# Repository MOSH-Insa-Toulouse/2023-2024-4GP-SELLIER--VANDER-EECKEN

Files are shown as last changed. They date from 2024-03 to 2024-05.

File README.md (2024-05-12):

<h1 align="center">📈 Projet capteur graphène 📉</h1>
<h2 align="center">👨‍🔬 Par VANDER-EECKEN Néo et SELLIÉ Pierre 👨‍🔬</h2>
<h3 align="center">🏫 Pour l'INSA de Toulouse, département du Génie Physique, année 2023 - 2024 🎓</h3>

<p align="center">
  <a href="http://www.gnu.org/licenses/gpl-3.0">
    
  </a>
</p>



<h1 align="center">🔩 Mesure de contrainte avec capteur graphène sous Arduino 🤖</h1>

## 📝 Description

Ce projet introduit une approche novatrice pour la mesure de contrainte en exploitant les propriétés uniques du graphène à travers un capteur dédié, envisagé comme une alternative prometteuse aux jauges de contrainte conventionnelles. Grâce à l'emploi du graphène, connu pour sa sensibilité et sa flexibilité, ce capteur offre un potentiel intéressant pour une variété d'applications de mesure. Le système est bâti autour d'une plateforme Arduino, facilitant ainsi son accessibilité et sa manipulation pour tous.

Le projet inclut un circuit d'amplification pour le signal du capteur en graphène, assurant une précision accrue des mesures. Un potentiomètre digital permet d'ajuster le gain de ce circuit, offrant ainsi une calibration précise selon les besoins spécifiques de l'application. Cette approche est complétée par des modules tels que le Bluetooth, un écran OLED et un encodeur rotatoire, qui enrichissent l'expérience utilisateur et la fonctionnalité du système.

En complément de la programmation Arduino, ce projet est accompagné de fichiers KiCad détaillant le design d'un Shield UNO personnalisé. Cette approche modulaire facilite le montage et l'intégration de l'ensemble des composants, permettant ainsi une grande flexibilité dans la configuration du système.

## 🌟 Fonctionnalités

- **Capteur de contrainte en graphène** : Exploite les propriétés du graphène pour une mesure de contrainte.
- **Circuit d'amplification avec réglage** : Potentiomètre digital pour ajuster le gain.
- **Modules intégrés** : Communication Bluetooth, affichage sur écran OLED et interaction utilisateur via encodeur rotatoire.
- **Design modulaire** : Fichiers KiCad pour un Shield UNO personnalisé.

Pour plus d'informations, vous pouvez retrouver la datasheet du produit [ici](https://github.com/MOSH-Insa-Toulouse/2023-2024-4GP-SELLIER--VANDER-EECKEN/blob/main/Datasheet.pdf).

## 📦 Matériel nécessaire

- Capteur graphène (à fabriquer soi-même)
- Arduino UNO (https://store.arduino.cc/products/arduino-uno-rev3)
- Circuit d'amplification : LTC1050#CN8 + 2x100kΩ ; 10kΩ ; 1kΩ ; 3x100nF ; 1µF (https://www.analog.com/en/products/ltc1050.html)
- Potentiomètre digital : MCP41050-IP (https://www.microchip.com/en-us/product/mcp41050)
- Module Bluetooth : HC-05 (https://www.gotronic.fr/art-module-bluetooth-hc05-26097.htm)
- Écran OLED : SSD1306 (https://electropeak.com/0-96-oled-64x128-display-module)
- Encodeur rotatoire (https://www.az-delivery.de/fr/products/drehimpulsgeber-modul)
- Capteur FLEX (https://www.kiwi-electronics.com/en/short-flex-bend-sensor-2172)

## 🔧 Installation

1. Assemblez le circuit selon les schémas fournis dans les fichiers KiCad.
2. Connectez les modules et le capteur en suivant le schéma KiCad.
3. Installez l'IDE Arduino et installez la librairie "U8glib"
4. Téléchargez le code source sur votre Arduino UNO.

## 🖥️ Utilisation

Utilisez l'encodeur rotatoire pour naviguer dans le menu de l'écran OLED.

## 🤝 Contribuer

Les contributions sont bienvenues ! Si vous avez des idées d'amélioration, n'hésitez pas à forker le projet, soumettre des pull requests ou ouvrir des issues.

## 📜 Licence

Distribué sous la GNU General Public License (GPL), favorisant un écosystème ouvert et collaboratif.

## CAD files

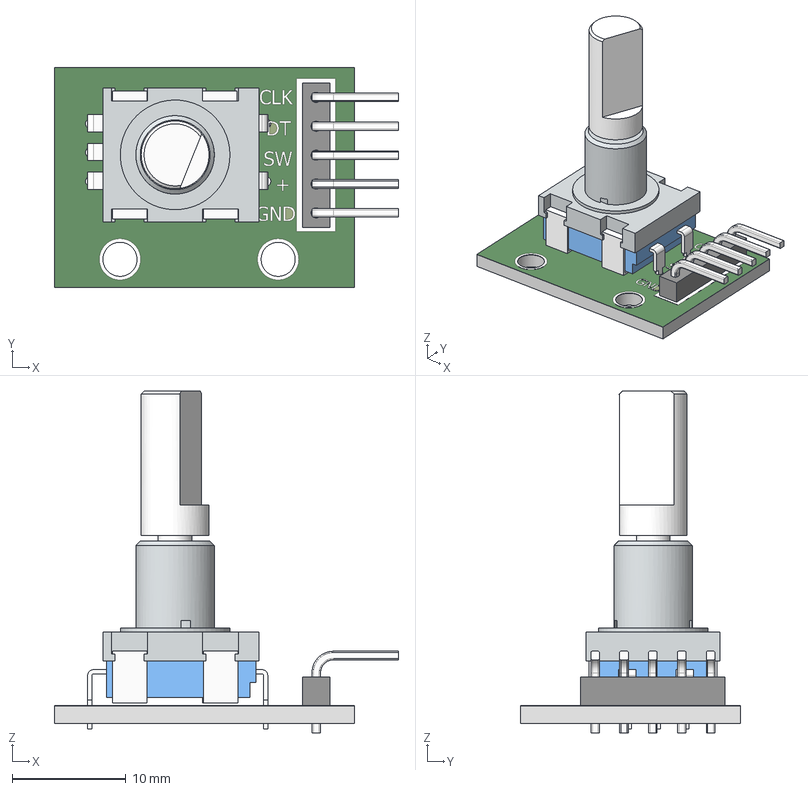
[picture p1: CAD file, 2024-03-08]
Fichiers KiCad/3D Models/KY-040.step
30.3 x 19.3 x 30.1 mm
pcb
mtg flange
body_encoder
5 pin header
90d pin_header x 5
decal_encoder
shaft_encoder

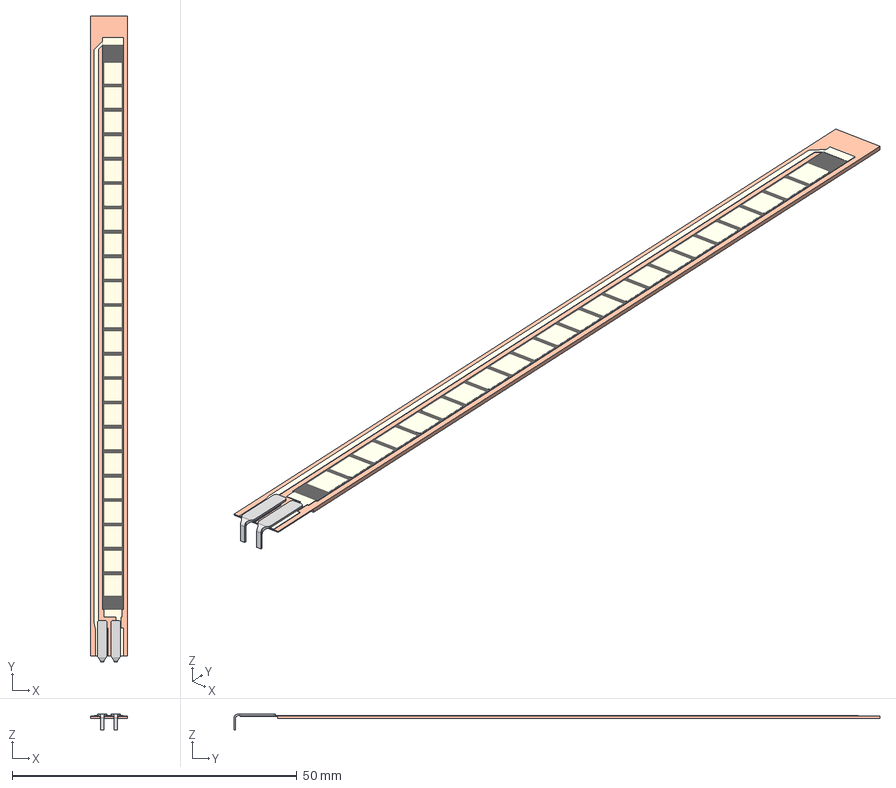
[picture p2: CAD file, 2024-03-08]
Fichiers KiCad/3D Models/Flex.stp
6.45 x 113.5 x 2.77 mm
FS-L-0095-103-ST - Base
FS-L-0095-103-ST - Top

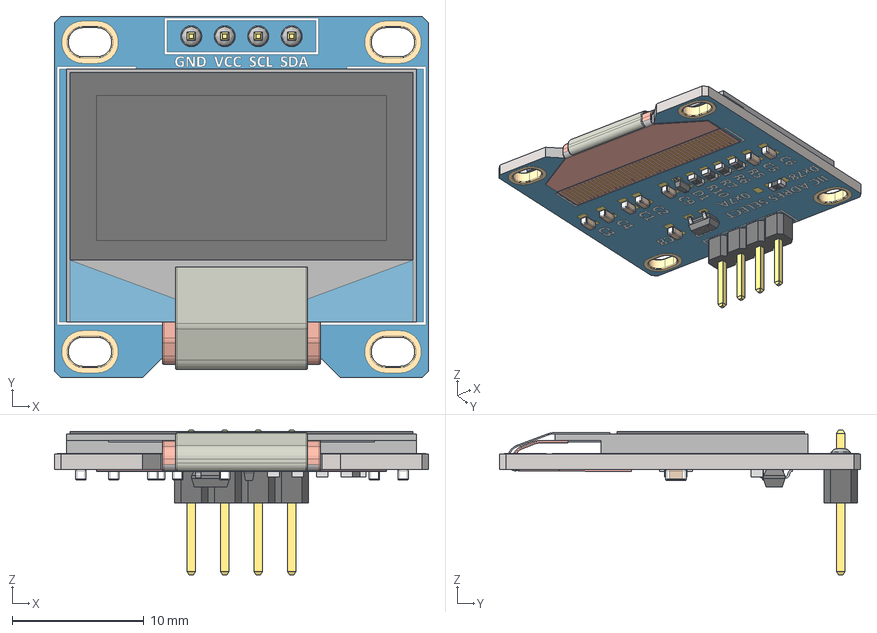
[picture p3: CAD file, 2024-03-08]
Fichiers KiCad/3D Models/SSD1306.stp
28.4 x 27.4 x 11.0 mm
SOT-23_TOR
RES_CR16_MTK_1 x 4
RES_CR16_MTK
SOD323F_DIO

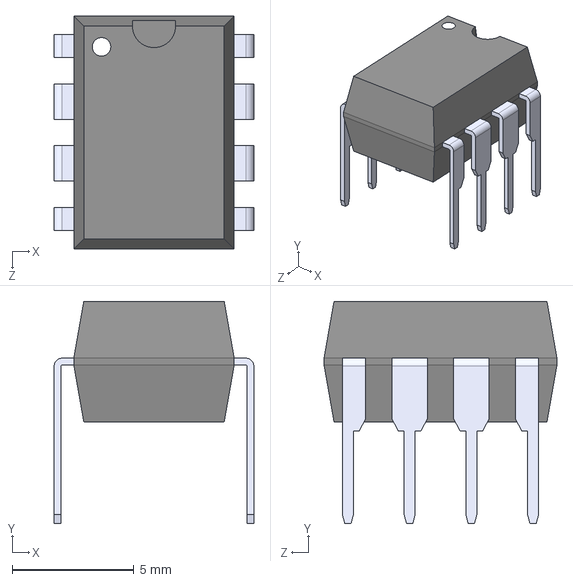
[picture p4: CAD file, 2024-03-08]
Fichiers KiCad/3D Models/LTC1050#CN8.step
8.22 x 9.14 x 9.59 mm

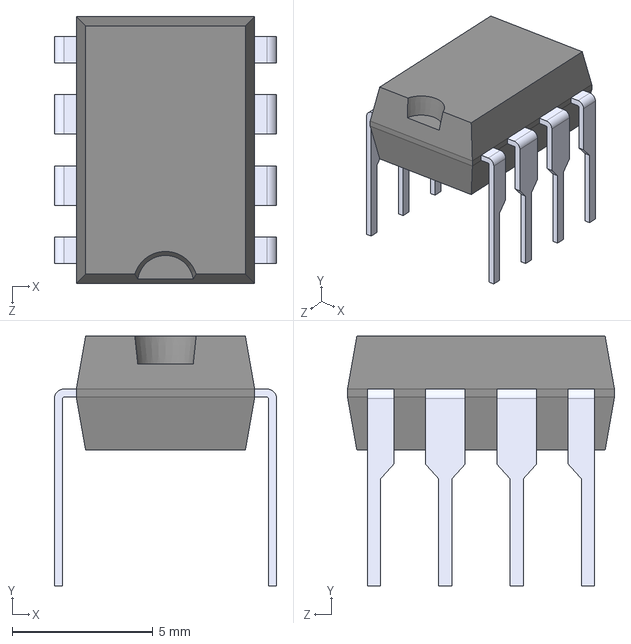
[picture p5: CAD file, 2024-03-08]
Fichiers KiCad/3D Models/MCP41050-I_P.step
7.91 x 8.89 x 9.50 mm

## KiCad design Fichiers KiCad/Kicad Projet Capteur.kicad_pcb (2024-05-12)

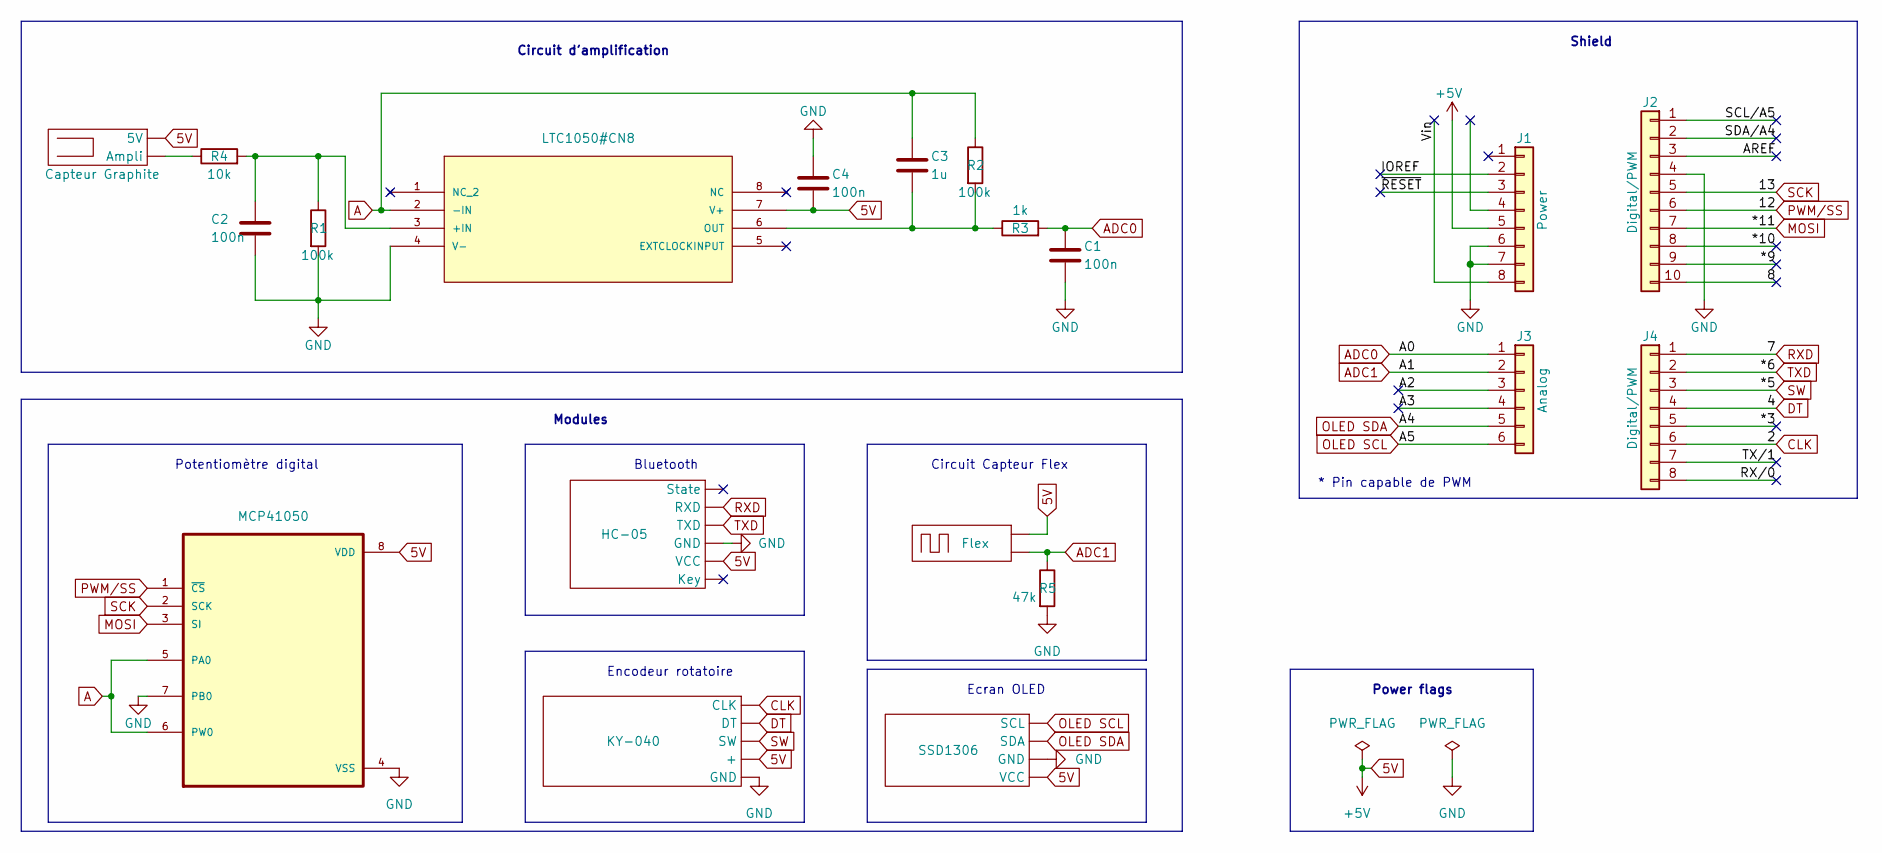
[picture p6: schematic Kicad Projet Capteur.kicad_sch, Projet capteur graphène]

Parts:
C1, C2, C4: 100n; C_Disc_D4.3mm_W1.9mm_P5.00mm
C3: 1u; C_Rect_L7.0mm_W4.5mm_P5.00mm
Capteur-Graphite1: Capteur Graphite; PinSocket_1x02_P2.54mm_Vertical
Flex1: Flex; PinSocket_1x02_P2.54mm_Vertical
HC-5: HC-05; PinSocket_1x06_P2.54mm_Vertical
J1: Power; PinSocket_1x08_P2.54mm_Vertical
J2: Digital/PWM; PinSocket_1x10_P2.54mm_Vertical
J3: Analog; PinSocket_1x06_P2.54mm_Vertical
J4: Digital/PWM; PinSocket_1x08_P2.54mm_Vertical
Pot1: KY-040; PinSocket_1x05_P2.54mm_Vertical
R1, R2: 100k; R_Axial_DIN0204_L3.6mm_D1.6mm_P5.08mm_Horizontal
R3: 1k; R_Axial_DIN0204_L3.6mm_D1.6mm_P5.08mm_Horizontal
R4: 10k; R_Axial_DIN0204_L3.6mm_D1.6mm_P5.08mm_Horizontal
R5: 47k; R_Axial_DIN0204_L3.6mm_D1.6mm_P5.08mm_Horizontal
SSD1306: SSD1306; PinSocket_1x04_P2.54mm_Vertical
U1: LTC1050#CN8; LTC1050; MANUFACTURER_PART_NUMBER ltc1050cn8
U2: MCP41050; MCP

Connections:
5V: C4.2, Capteur-Graphite1.1 (5V), Flex1.1 (+), HC-5.5 (VCC), J1.5, Pot1.4 (+), SSD1306.4 (VCC), U1.7 (V+), U2.8 (VDD)
/8: J2.10
/*3: J4.5
/*9: J2.9
/*10: J2.8
/A2: J3.3
/A3: J3.4
/AREF: J2.3
/IOREF: J1.2
/RX/0: J4.8
/SCL/A5: J2.1
/SDA/A4: J2.2
/TX/1: J4.7
/Vin: J1.8
/~RESET: J1.3
A: C3.1, R2.1, U1.2 (-IN), U2.5 (PA0), U2.6 (PW0)
ADC0: C1.1, J3.1, R3.2
ADC1: Flex1.2 (-), J3.2, R5.1
CLK: J4.6, Pot1.1 (CLK)
DT: J4.4, Pot1.2 (DT)
GND: C1.2, C2.2, C4.1, HC-5.4 (GND), J1.6, J1.7, J2.4, Pot1.5 (GND), R1.2, R5.2, SSD1306.3 (GND), U1.4 (V-), U2.4 (VSS), U2.7 (PB0)
MOSI: J2.7, U2.3 (SI)
unnamed: Capteur-Graphite1.2 (Ampli), R4.1
unnamed: C2.1, R1.1, R4.2, U1.3 (+IN)
unnamed: C3.2, R2.2, R3.1, U1.6 (OUT)
OLED SCL: J3.6, SSD1306.1 (SCL)
OLED SDA: J3.5, SSD1306.2 (SDA)
PWM/SS: J2.6, U2.1 (~CS)
RXD: HC-5.2 (RXD), J4.1
SCK: J2.5, U2.2 (SCK)
SW: J4.3, Pot1.3 (SW)
TXD: HC-5.3 (TXD), J4.2

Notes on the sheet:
Potentiomètre digital
Circuit d'amplification
Power flags
Bluetooth
Ecran OLED
Circuit Capteur Flex
* Pin capable de PWM
Modules
Shield
Encodeur rotatoire

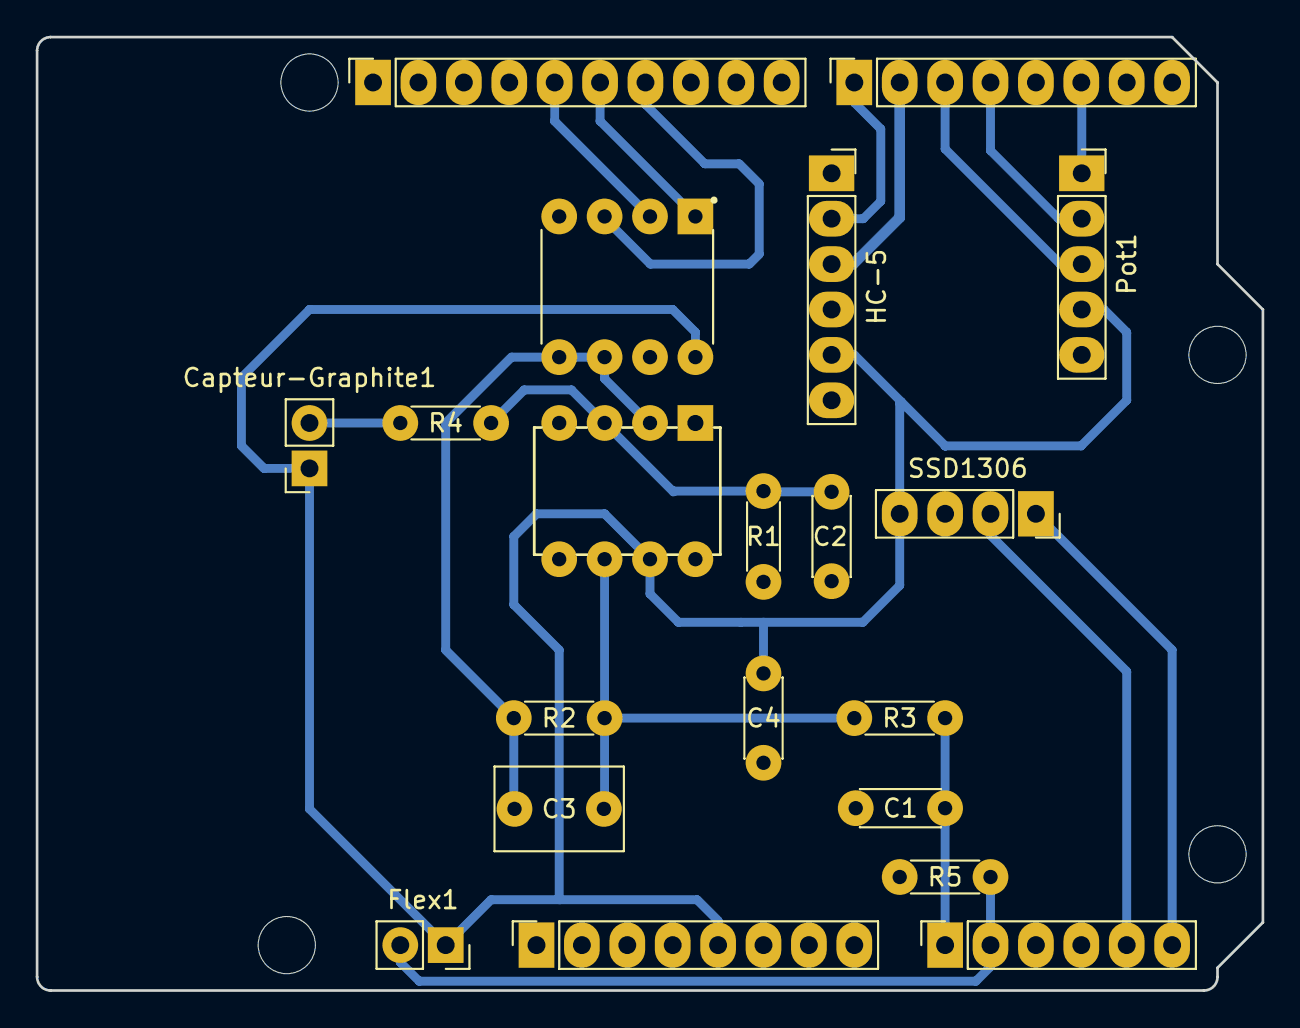
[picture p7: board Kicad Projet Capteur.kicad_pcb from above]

Board: 2 copper layers, 68.6 x 53.3 mm, 24 parts (0 on the bottom side), 18 nets.

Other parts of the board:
MH1, MH2, MH3, MH4: MountingHole_3.2mm

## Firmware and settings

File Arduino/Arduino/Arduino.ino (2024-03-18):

#include <SoftwareSerial.h>
#include <SPI.h>
#include "U8glib.h"

// Définitions des broches
#define CLK 2 // Broche 2 en tant que CLK, raccordé sur CLK du KY-040
#define DT 4 // Broche 4 en tant que DT, raccordé sur DT du KY-040
#define SW 5 // Broche 5 en tant que SW, raccordé sur SW du KY-040
#define txPin 6 // Broche 6 en tant que TX, raccordé sur TX du HC-05
#define rxPin 7 // Broche 7 en tant que RX, raccordé sur RX du HC-05
#define SS 12 // Broche 12 en tant que SS, raccordé sur SS du MCP41050
#define Ampli A0 // Broche A0 en tant que Ampli, raccordé sur la sortie du LTC1050#CN8
#define Flex A1 // Broche A1 en tant que Flex, raccordé sur le pont diviseur du capteur Flex

#define baudrate 9600 // Définition du BaudRate général
SoftwareSerial mySerial(rxPin ,txPin); // Définition du software serial

#define delai_inter_image 6 // Définition pour les animations

// Variables pour le MCP41050
const double R_max = 50000.0; // Résistance maximale du MCP41050
const double R_min = 0.0; // Résistance minimale du MCP41050
const double R_amp = 100000.0; // Résistance en sortie de l'amplificateur
const double R_wiper = 125.0; // Résistance interne du MCP41050
const double gain_max = 801; // 1 + R_amp/(R_min+R_wiper)
const double gain_min = 3; // 1 + R_amp/(R_max+R_wiper)
double R_mcp = R_max - R_wiper; // Résistance du MCP41050, par défaut maximale
double gain = 3; // Gain par défaut, le gain vaut 1 + R_amp/(R_mcp + R_wiper)
double ancien_gain = 3; // Variable utilisée pour checker un changement de gain

// Initilisation de l'écran
U8GLIB_SSD1306_128X64 u8g(U8G_I2C_OPT_DEV_0 | U8G_I2C_OPT_NO_ACK | U8G_I2C_OPT_FAST);

// Variables pour le KY-040
volatile unsigned int Pos_encodeur = 0; // Variable de l'encodeur
unsigned int ancienne_pos = 0; // Variable utilisée pour checker un changement de position de l'encodeur
// Variables pour le debounce du bouton
int etatBouton = HIGH; // L'état actuel du bouton (HIGH = non pressé, LOW = pressé)
int dernierEtatBouton = HIGH; // Le dernier état stable du bouton
unsigned long dernierTempsDebounce = 0; // Le dernier temps où le bouton a changé d'état
unsigned long intervalleDebounce = 50; // L'intervalle de debounce en millisecondes

// Variables pour le Flex
const float VCC = 5; // Tension de l'Arduino
const float R_DIV = 47000.0; // Résistance utilisée dans le pont diviseur
const float R_plat = 25000.0; // Résistance à plat
const float R_pli = 100000.0; // Résistance à 90°
float R_flex; // Résistance actuelle du FLEX

// Variable pour le capteur
const float R1 = 100000.0;
const float R2 = 100000.0;
const float R4 = 10000.0;
float R_capt;

// Variables pour le menu
const int nbr_items = 3; // Nombre d'items dans le menu principal
const int taille_max_items = 20; // Taille maximale des items
int item_actuel = 0; // Item du menu séléctionné
int ecran_actuel = 0; // 0 = Menu, 1 = Amplification, 2 = Valeurs

// Icône paramètre
const unsigned char bitmap_icone_param [] PROGMEM = {
  0x00, 0x00, 0x01, 0x80, 0x03, 0xc0, 0x16, 0x68, 0x3c, 0x3c, 0x21, 0x84, 0x33, 0xcc, 0x16, 0x68, 
	0x16, 0x68, 0x33, 0xcc, 0x21, 0x84, 0x3c, 0x3c, 0x16, 0x68, 0x03, 0xc0, 0x01, 0x80, 0x00, 0x00
};

// Icône graphique
const unsigned char bitmap_icone_graph [] PROGMEM = {
  0x00, 0x00, 0x80, 0x00, 0x84, 0x00, 0xa4, 0x00, 0x82, 0x00, 0xc2, 0x00, 0xc1, 0x00, 0x81, 0x00, 
	0x80, 0x00, 0x80, 0x82, 0x80, 0x82, 0x80, 0x00, 0x80, 0x44, 0x80, 0x28, 0x80, 0x00, 0x00, 0x00
};

// Icône reset
const unsigned char bitmap_icone_reset [] PROGMEM = {
  0x00, 0xc0, 0x00, 0xf0, 0xf0, 0x18, 0x30, 0x04, 0x70, 0x06, 0x50, 0x02, 0xc0, 0x03, 0xc0, 0x03, 
	0xc0, 0x03, 0xc0, 0x03, 0x40, 0x02, 0x60, 0x06, 0x20, 0x04, 0x18, 0x18, 0x0f, 0xf0, 0x03, 0xc0
};

// Tableau des bitmaps
const unsigned char* bitmap_icones[3] = {
  bitmap_icone_param,
  bitmap_icone_graph,
  bitmap_icone_reset
};

// Barre de défilement
const unsigned char bitmap_barre [] PROGMEM = {
  0x00, 0x02, 0x00, 0x02, 0x00, 0x02, 0x00, 0x02, 0x00, 0x02, 0x00, 0x02, 0x00, 0x02, 0x00, 0x02, 
  0x00, 0x02, 0x00, 0x02, 0x00, 0x02, 0x00, 0x02, 0x00, 0x02, 0x00, 0x02, 0x00, 0x02, 0x00, 0x02, 
  0x00, 0x02, 0x00, 0x02, 0x00, 0x02, 0x00, 0x02, 0x00, 0x02, 0x00, 0x02, 0x00, 0x02, 0x00, 0x02, 
  0x00, 0x02, 0x00, 0x02, 0x00, 0x02, 0x00, 0x02, 0x00, 0x02, 0x00, 0x02, 0x00, 0x02, 0x00, 0x00
};

// Entourer l'élément sélectionné
const unsigned char bitmap_item_actuel [] PROGMEM = {
  0x1f, 0xff, 0xff, 0xff, 0xff, 0xff, 0xff, 0xff, 0xff, 0xff, 0xff, 0xff, 0xff, 0xff, 0xff, 0xc0, 
  0x20, 0x00, 0x00, 0x00, 0x00, 0x00, 0x00, 0x00, 0x00, 0x00, 0x00, 0x00, 0x00, 0x00, 0x00, 0x20, 
  0x40, 0x00, 0x00, 0x00, 0x00, 0x00, 0x00, 0x00, 0x00, 0x00, 0x00, 0x00, 0x00, 0x00, 0x00, 0x30, 
  0x40, 0x00, 0x00, 0x00, 0x00, 0x00, 0x00, 0x00, 0x00, 0x00, 0x00, 0x00, 0x00, 0x00, 0x00, 0x30, 
  0x40, 0x00, 0x00, 0x00, 0x00, 0x00, 0x00, 0x00, 0x00, 0x00, 0x00, 0x00, 0x00, 0x00, 0x00, 0x30, 
  0x40, 0x00, 0x00, 0x00, 0x00, 0x00, 0x00, 0x00, 0x00, 0x00, 0x00, 0x00, 0x00, 0x00, 0x00, 0x30, 
  0x40, 0x00, 0x00, 0x00, 0x00, 0x00, 0x00, 0x00, 0x00, 0x00, 0x00, 0x00, 0x00, 0x00, 0x00, 0x30, 
  0x40, 0x00, 0x00, 0x00, 0x00, 0x00, 0x00, 0x00, 0x00, 0x00, 0x00, 0x00, 0x00, 0x00, 0x00, 0x30, 
  0x40, 0x00, 0x00, 0x00, 0x00, 0x00, 0x00, 0x00, 0x00, 0x00, 0x00, 0x00, 0x00, 0x00, 0x00, 0x30, 
  0x40, 0x00, 0x00, 0x00, 0x00, 0x00, 0x00, 0x00, 0x00, 0x00, 0x00, 0x00, 0x00, 0x00, 0x00, 0x30, 
  0x40, 0x00, 0x00, 0x00, 0x00, 0x00, 0x00, 0x00, 0x00, 0x00, 0x00, 0x00, 0x00, 0x00, 0x00, 0x30, 
  0x40, 0x00, 0x00, 0x00, 0x00, 0x00, 0x00, 0x00, 0x00, 0x00, 0x00, 0x00, 0x00, 0x00, 0x00, 0x30, 
  0x40, 0x00, 0x00, 0x00, 0x00, 0x00, 0x00, 0x00, 0x00, 0x00, 0x00, 0x00, 0x00, 0x00, 0x00, 0x30, 
  0x40, 0x00, 0x00, 0x00, 0x00, 0x00, 0x00, 0x00, 0x00, 0x00, 0x00, 0x00, 0x00, 0x00, 0x00, 0x30, 
  0x40, 0x00, 0x00, 0x00, 0x00, 0x00, 0x00, 0x00, 0x00, 0x00, 0x00, 0x00, 0x00, 0x00, 0x00, 0x30, 
  0x40, 0x00, 0x00, 0x00, 0x00, 0x00, 0x00, 0x00, 0x00, 0x00, 0x00, 0x00, 0x00, 0x00, 0x00, 0x30, 
  0x40, 0x00, 0x00, 0x00, 0x00, 0x00, 0x00, 0x00, 0x00, 0x00, 0x00, 0x00, 0x00, 0x00, 0x00, 0x30, 
  0x40, 0x00, 0x00, 0x00, 0x00, 0x00, 0x00, 0x00, 0x00, 0x00, 0x00, 0x00, 0x00, 0x00, 0x00, 0x30, 
  0x40, 0x00, 0x00, 0x00, 0x00, 0x00, 0x00, 0x00, 0x00, 0x00, 0x00, 0x00, 0x00, 0x00, 0x00, 0x30, 
  0x3f, 0xff, 0xff, 0xff, 0xff, 0xff, 0xff, 0xff, 0xff, 0xff, 0xff, 0xff, 0xff, 0xff, 0xff, 0xe0, 
  0x1f, 0xff, 0xff, 0xff, 0xff, 0xff, 0xff, 0xff, 0xff, 0xff, 0xff, 0xff, 0xff, 0xff, 0xff, 0xc0
};

// Array qui contient les noms des menus
char items_menu [nbr_items] [taille_max_items] = {
  {"Amplification"}, 
  {"Valeurs"},
  {"Reset"}
};

// Animation "validé"
const byte PROGMEM images_valide[][288] = {
  {0,0,0,0,0,0,0,0,0,0,0,0,0,0,0,0,0,0,0,0,0,0,0,0,0,0,0,0,0,0,0,0,0,0,0,0,0,0,0,0,0,0,0,0,0,0,0,0,0,0,0,0,0,0,0,0,0,0,0,0,0,0,0,0,0,0,0,0,0,0,0,0,0,0,0,0,0,0,0,0,0,0,0,0,0,0,0,0,0,0,0,0,0,0,0,0,0,0,0,0,0,0,0,0,0,0,0,0,0,0,0,0,0,0,0,0,0,0,0,0,0,0,0,0,0,0,0,0,0,0,0,0,0,0,0,0,0,0,0,0,0,0,0,0,0,0,0,0,0,0,0,0,0,0,0,0,0,0,0,0,0,0,3,0,0,0,0,0,3,128,0,0,0,0,1,192,0,0,0,0,0,224,0,0,0,0,0,112,0,0,0,0,0,60,0,0,0,0,0,30,0,0,0,0,0,7,0,0,0,0,0,3,128,0,0,0,0,1,128,0,0,0,0,0,128,0,0,0,0,0,0,0,0,0,0,0,0,0,0,0,0,0,0,0,0,0,0,0,0,0,0,0,0,0,0,0,0,0,0,0,0,0,0,0,0,0,0,0,0,0,0,0,0,0,0,0,0,0,0,0,0,0,0,0,0,0,0,0},
  {0,0,0,0,0,0,0,0,0,0,0,0,0,0,0,0,0,0,0,0,0,0,0,0,0,0,0,0,0,0,0,0,0,0,0,0,0,0,0,0,0,0,0,0,0,0,0,0,0,0,0,0,0,0,0,0,0,0,0,0,0,0,0,0,0,0,0,0,0,0,0,0,0,0,0,0,0,0,0,0,0,0,0,0,0,0,0,0,0,0,0,0,0,0,0,0,0,0,0,0,0,0,0,0,0,0,0,0,0,0,0,0,0,0,0,0,0,0,0,0,0,0,0,0,0,0,0,0,0,0,0,0,0,0,0,0,0,0,0,0,0,0,0,0,0,0,0,0,0,0,0,0,0,0,0,0,0,0,0,0,0,0,3,0,0,0,0,0,3,128,0,0,0,0,1,192,0,0,0,0,0,224,0,0,0,0,0,112,0,0,0,0,0,60,0,96,0,0,0,30,0,224,0,0,0,7,0,192,0,0,0,3,129,192,0,0,0,1,195,128,0,0,0,0,227,0,0,0,0,0,119,0,0,0,0,0,62,0,0,0,0,0,28,0,0,0,0,0,0,0,0,0,0,0,0,0,0,0,0,0,0,0,0,0,0,0,0,0,0,0,0,0,0,0,0,0,0,0,0,0,0,0,0,0,0,0,0,0},
  {0,0,0,0,0,0,0,0,0,0,0,0,0,0,0,0,0,0,0,0,0,0,0,0,0,0,0,0,0,0,0,0,0,0,0,0,0,0,0,0,0,0,0,0,0,0,0,0,0,0,0,0,0,0,0,0,0,0,0,0,0,0,0,0,0,0,0,0,0,0,0,0,0,0,0,0,0,0,0,0,0,0,0,0,0,0,0,0,0,0,0,0,0,0,0,0,0,0,0,0,0,0,0,0,0,0,0,0,0,0,0,0,0,0,0,0,0,0,0,0,0,0,0,0,0,0,0,0,0,0,0,0,0,0,0,0,0,0,0,0,0,1,128,0,0,0,0,3,128,0,0,0,0,3,0,0,0,0,0,6,0,0,3,0,0,14,0,0,3,128,0,12,0,0,1,192,0,28,0,0,0,224,0,56,0,0,0,112,0,48,0,0,0,60,0,112,0,0,0,30,0,224,0,0,0,7,0,192,0,0,0,3,129,192,0,0,0,1,195,128,0,0,0,0,227,0,0,0,0,0,119,0,0,0,0,0,62,0,0,0,0,0,28,0,0,0,0,0,0,0,0,0,0,0,0,0,0,0,0,0,0,0,0,0,0,0,0,0,0,0,0,0,0,0,0,0,0,0,0,0,0,0,0,0,0,0,0,0},
  {0,0,0,0,0,0,0,0,0,0,0,0,0,0,0,0,0,0,0,0,0,0,0,0,0,0,0,0,0,0,0,0,0,0,0,0,0,0,0,0,0,0,0,0,0,0,0,0,0,0,0,0,0,0,0,0,0,0,0,0,0,0,0,0,0,0,0,0,0,0,0,0,0,0,0,0,0,0,0,0,0,0,0,0,0,0,0,0,0,0,0,0,0,0,0,0,0,0,0,0,0,0,0,0,0,0,24,0,0,0,0,0,56,0,0,0,0,0,112,0,0,0,0,0,96,0,0,0,0,0,224,0,0,0,0,0,192,0,0,0,0,1,128,0,0,0,0,3,128,0,0,0,0,3,0,0,0,0,0,6,0,0,3,0,0,14,0,0,3,128,0,12,0,0,1,192,0,24,0,0,0,240,0,56,0,0,0,120,0,48,0,0,0,60,0,112,0,0,0,14,0,224,0,0,0,7,0,192,0,0,0,3,129,192,0,0,0,1,193,128,0,0,0,0,227,0,0,0,0,0,119,0,0,0,0,0,62,0,0,0,0,0,28,0,0,0,0,0,0,0,0,0,0,0,0,0,0,0,0,0,0,0,0,0,0,0,0,0,0,0,0,0,0,0,0,0,0,0,0,0,0,0,0,0,0,0,0,0},
  {0,0,0,0,0,0,0,0,0,0,0,0,0,0,0,0,0,0,0,0,0,0,0,0,0,0,0,0,0,0,0,0,0,0,0,0,0,0,0,0,0,0,0,0,0,0,0,0,0,0,0,0,0,0,0,0,0,0,0,0,0,0,0,0,0,0,0,0,0,0,0,0,0,0,0,0,0,0,0,0,0,0,7,0,0,0,0,0,6,0,0,0,0,0,12,0,0,0,0,0,28,0,0,0,0,0,24,0,0,0,0,0,56,0,0,0,0,0,112,0,0,0,0,0,96,0,0,0,0,0,224,0,0,0,0,0,192,0,0,0,0,1,128,0,0,0,0,3,128,0,0,0,0,3,0,0,0,0,0,6,0,0,3,0,0,14,0,0,3,128,0,12,0,0,1,192,0,24,0,0,0,240,0,56,0,0,0,120,0,48,0,0,0,60,0,112,0,0,0,14,0,224,0,0,0,7,0,192,0,0,0,3,129,192,0,0,0,1,193,128,0,0,0,0,227,0,0,0,0,0,119,0,0,0,0,0,62,0,0,0,0,0,28,0,0,0,0,0,0,0,0,0,0,0,0,0,0,0,0,0,0,0,0,0,0,0,0,0,0,0,0,0,0,0,0,0,0,0,0,0,0,0,0,0,0,0,0,0},
  {0,0,0,0,0,0,0,0,0,0,0,0,0,0,0,0,0,0,0,0,0,0,0,0,0,0,0,0,0,0,0,0,0,0,0,0,0,0,0,0,0,0,0,0,0,0,0,0,0,0,0,0,0,0,0,0,0,0,0,0,0,0,0,0,1,128,0,0,0,0,1,128,0,0,0,0,3,0,0,0,0,0,7,0,0,0,0,0,6,0,0,0,0,0,14,0,0,0,0,0,28,0,0,0,0,0,24,0,0,0,0,0,56,0,0,0,0,0,112,0,0,0,0,0,96,0,0,0,0,0,224,0,0,0,0,1,192,0,0,0,0,1,128,0,0,0,0,3,128,0,0,0,0,3,0,0,0,0,0,6,0,0,3,0,0,14,0,0,3,128,0,12,0,0,1,192,0,28,0,0,0,224,0,56,0,0,0,112,0,48,0,0,0,60,0,112,0,0,0,30,0,224,0,0,0,7,0,192,0,0,0,3,129,192,0,0,0,1,195,128,0,0,0,0,227,0,0,0,0,0,119,0,0,0,0,0,62,0,0,0,0,0,28,0,0,0,0,0,0,0,0,0,0,0,0,0,0,0,0,0,0,0,0,0,0,0,0,0,0,0,0,0,0,0,0,0,0,0,0,0,0,0,0,0,0,0,0,0},
  {0,0,0,0,0,0,0,0,0,0,0,0,0,0,0,0,0,0,0,0,0,0,0,0,0,0,0,0,0,0,0,0,0,0,0,0,0,0,0,0,0,0,0,0,0,0,0,0,0,0,0,0,0,0,0,0,0,0,0,192,0,0,0,0,1,192,0,0,0,0,1,128,0,0,0,0,3,0,0,0,0,0,7,0,0,0,0,0,6,0,0,0,0,0,14,0,0,0,0,0,28,0,0,0,0,0,24,0,0,0,0,0,56,0,0,0,0,0,112,0,0,0,0,0,96,0,0,0,0,0,224,0,0,0,0,1,192,0,0,0,0,1,128,0,0,0,0,3,128,0,0,0,0,3,0,0,0,0,0,6,0,0,3,0,0,14,0,0,3,128,0,12,0,0,1,192,0,28,0,0,0,224,0,56,0,0,0,112,0,48,0,0,0,60,0,112,0,0,0,30,0,224,0,0,0,7,0,192,0,0,0,3,129,192,0,0,0,1,195,128,0,0,0,0,227,0,0,0,0,0,119,0,0,0,0,0,62,0,0,0,0,0,28,0,0,0,0,0,0,0,0,0,0,0,0,0,0,0,0,0,0,0,0,0,0,0,0,0,0,0,0,0,0,0,0,0,0,0,0,0,0,0,0,0,0,0,0,0},
  {0,0,0,0,0,0,0,0,0,0,0,0,0,0,0,0,0,0,0,0,0,0,0,0,0,0,0,0,0,0,0,0,0,0,0,0,0,0,0,0,0,0,0,0,0,0,0,0,0,0,0,0,0,64,0,0,0,0,0,192,0,0,0,0,1,192,0,0,0,0,1,128,0,0,0,0,3,0,0,0,0,0,7,0,0,0,0,0,6,0,0,0,0,0,14,0,0,0,0,0,28,0,0,0,0,0,24,0,0,0,0,0,56,0,0,0,0,0,112,0,0,0,0,0,96,0,0,0,0,0,224,0,0,0,0,1,192,0,0,0,0,1,128,0,0,0,0,3,128,0,0,0,0,3,0,0,0,0,0,6,0,0,3,0,0,14,0,0,3,128,0,12,0,0,1,192,0,28,0,0,0,224,0,56,0,0,0,112,0,48,0,0,0,60,0,112,0,0,0,30,0,224,0,0,0,7,0,192,0,0,0,3,129,192,0,0,0,1,195,128,0,0,0,0,227,0,0,0,0,0,119,0,0,0,0,0,62,0,0,0,0,0,28,0,0,0,0,0,0,0,0,0,0,0,0,0,0,0,0,0,0,0,0,0,0,0,0,0,0,0,0,0,0,0,0,0,0,0,0,0,0,0,0,0,0,0,0,0},
  {0,0,0,0,0,0,0,0,0,0,0,0,0,0,0,0,0,0,0,0,0,0,0,0,0,0,0,0,0,0,0,0,0,0,0,0,0,0,0,0,0,0,0,0,0,0,0,0,0,0,0,0,0,64,0,0,0,0,0,192,0,0,0,0,1,192,0,0,0,0,1,128,0,0,0,0,3,0,0,0,0,0,7,0,0,0,0,0,6,0,0,0,0,0,14,0,0,0,0,0,28,0,0,0,0,0,24,0,0,0,0,0,56,0,0,0,0,0,112,0,0,0,0,0,96,0,0,0,0,0,224,0,0,0,0,1,192,0,0,0,0,1,128,0,0,0,0,3,128,0,0,0,0,3,0,0,0,0,0,6,0,0,3,0,0,14,0,0,3,128,0,12,0,0,1,192,0,28,0,0,0,224,0,56,0,0,0,112,0,48,0,0,0,60,0,112,0,0,0,30,0,224,0,0,0,7,0,192,0,0,0,3,129,192,0,0,0,1,195,128,0,0,0,0,227,0,0,0,0,0,119,0,0,0,0,0,62,0,0,0,0,0,28,0,0,0,0,0,0,0,0,0,0,0,0,0,0,0,0,0,0,0,0,0,0,0,0,0,0,0,0,0,0,0,0,0,0,0,0,0,0,0,0,0,0,0,0,0},
  {0,0,0,0,0,0,0,0,0,0,0,0,0,0,0,0,0,0,0,0,0,0,0,0,0,0,0,0,0,0,0,0,0,0,0,0,0,0,0,0,0,0,0,0,0,0,0,0,0,0,0,0,0,64,0,0,0,0,0,192,0,0,0,0,1,192,0,0,0,0,1,128,0,0,0,0,3,0,0,0,0,0,7,0,0,0,0,0,6,0,0,0,0,0,14,0,0,0,0,0,28,0,0,0,0,0,24,0,0,0,0,0,56,0,0,0,0,0,112,0,0,0,0,0,96,0,0,0,0,0,224,0,0,0,0,1,192,0,0,0,0,1,128,0,0,0,0,3,128,0,0,0,0,3,0,0,0,0,0,6,0,0,3,0,0,14,0,0,3,128,0,12,0,0,1,192,0,28,0,0,0,224,0,56,0,0,0,112,0,48,0,0,0,60,0,112,0,0,0,30,0,224,0,0,0,7,0,192,0,0,0,3,129,192,0,0,0,1,195,128,0,0,0,0,227,0,0,0,0,0,119,0,0,0,0,0,62,0,0,0,0,0,28,0,0,0,0,0,0,0,0,0,0,0,0,0,0,0,0,0,0,0,0,0,0,0,0,0,0,0,0,0,0,0,0,0,0,0,0,0,0,0,0,0,0,0,0,0},
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
void loop() {

  /////////////////////////PARTIE MCP41050/////////////////////////
  
  // Changement de la résistance du MCP41050
  if (ancien_gain != gain) { // Si détection de changement de gain
    R_mcp = (R_amp / (gain - 1.0)) - R_wiper; // Calcule la nouvelle résistance R_mcp
    int valeur_mcp = int((gain_max - gain) / (gain_max - gain_min) * 255 + 0.5); // Mapage entre 0 et 255 au plus proche
    EcritureSPI(valeur_mcp, SS); // Envoi vers le MCP41050
    ancien_gain = gain; // Mise à jour la valeur de l'ancien gain
  }

  /////////////////////////PARTIE CAPTEUR/////////////////////////

  float V_ADC = analogRead(Ampli);
  R_capt = ((1+R2/(R_mcp+R_wiper))*R1*VCC/V_ADC)-R1-R4;
  
  /////////////////////////PARTIE FLEX/////////////////////////

  R_flex = Flex_read(); // Donne la résistance du FLEX
  // METTRE L'ENVOI DU BLUETOOTH

  /////////////////////////PARTIE KYC-040/////////////////////////

  noInterrupts(); // Désactive les interruptions pour une lecture atomique
  unsigned int posActuelle = Pos_encodeur; // Copie atomique de Pos_encodeur
  interrupts(); // Réactive les interruptions

  // Logique de navigation dans le menu avec l'encodeur
  if (ecran_actuel == 0) { // La navigation dans le menu est active seulement si ecran_actuel == 0
    if (posActuelle != ancienne_pos) { // Si l'on détecte un changement
      if (posActuelle > ancienne_pos) { // Rotation vers le haut
        item_actuel--;
        if (item_actuel < 0) {
          item_actuel = nbr_items - 1; // Boucle au dernier élément si on dépasse le premier
        }
      } else { // Rotation vers le bas
        item_actuel++;
        if (item_actuel >= nbr_items) {
          item_actuel = 0; // Boucle au premier élément si on dépasse le dernier
        }
      }
      ancienne_pos = posActuelle; // Mise à jour de l'ancienne position
    }
  }

  int lectureBouton = digitalRead(SW); // On lit l'état du bouton
  if (lectureBouton != dernierEtatBouton) { // S'il est différent
    dernierTempsDebounce = millis(); // On timestamp le moment où il est appuyé
  }
  if ((millis() - dernierTempsDebounce) > intervalleDebounce) { // S'il est appuyé pendant un certain nombre de millisecondes
    if (lectureBouton != etatBouton) { // Si l'état du bouton a changé
      etatBouton = lectureBouton; // On modifie l'état
      if (etatBouton == LOW) { // Si le bouton est effectivement pressé
        if (ecran_actuel == 0) { // Si on est sur le menu
          if (item_actuel == 2) { //Si on est sur le bouton reset
            asm volatile ("  jmp 0"); // Reset de la carte
          } else {
            ecran_actuel = item_actuel + 1; // On va dans l'écran de l'item séléctionné
          }
        } else {
          ecran_actuel = 0; // On revient au menu principal
        }
      }
    }
  }
  dernierEtatBouton = lectureBouton; // On met à jour l'ancien état

  /////////////////////////PARTIE BLUETOOTH/////////////////////////

  bluetooth_gain(); // Check si le gain n'est pas mis à jour par l'application
  envoie_bluetooth(R_capt, R_flex); // On envoie les données par bluetooth

  /////////////////////////PARTIE OLED/////////////////////////

  menu_page(item_actuel, gain, R_capt, R_flex); // On écrit sur le menu
}

// Fonction qui retourne un float ayant pour valeur la résistance du FLEX
float Flex_read() {
  float Vflex = analogRead(Flex) * VCC / 1023.0; // Lecture de la tension aux bornes du FLEX
  float R_flex = R_DIV * (VCC / Vflex - 1.0); // Calcul de la résistance du FLEX
  //float angle = (R_flex - R_plat) * (90.0 - 0) / (R_pli - R_plat) + 0; // Estimation de l'angle du FLEX
  return R_flex;
}

// Pour envoyer les données au MCP41050
void EcritureSPI(uint8_t valeur, uint8_t ssPin) {
  uint8_t cmd = 0x11; // Commande d'écriture pour MCP41050
  digitalWrite(ssPin, LOW); // Sélection du chip
  SPI.transfer(cmd); // Envoyer la commande d'écriture
  SPI.transfer(valeur); // Envoyer la valeur associée
  digitalWrite(ssPin, HIGH); // Désélection du chip
}

// Fonction d'interrupt qui modifie l'état la variable de position lorsqu'il change
void Encodeur_interrupt() {
  if (digitalRead(DT)==HIGH) { // Si l'on tourne à droite
    Pos_encodeur++; // On incrémente "Pos_encodeur"
  } else { // Si l'on tourne à gauche
    Pos_encodeur--; // On décrémente "Pos_encodeur"
  }
}

void menu_page(int item_actuel, int gain, float R_capt, float R_flex){
  u8g.firstPage(); // Nécessaire
  do {
    // Ecran menu
    if (ecran_actuel == 0) {
      // Tour d'item sélectionné
      u8g.drawBitmapP(0, 64/nbr_items * item_actuel + item_actuel, 128/8, 21, bitmap_item_actuel);

      // Police
      u8g.setFont(u8g_font_7x14);

      // Amplification
      u8g.drawStr(25, 15, items_menu[0]); 
      u8g.drawBitmapP( 4, 2, 16/8, 16, bitmap_icones[0]);          

      // Valeurs
      u8g.drawStr(25, 15+20+2, items_menu[1]);   
      u8g.drawBitmapP( 4, 24, 16/8, 16, bitmap_icones[1]);     

      // Reset    
      u8g.drawStr(25, 15+20+20+2+2, items_menu[2]);   
      u8g.drawBitmapP( 4, 46, 16/8, 16, bitmap_icones[2]);  

      // Barre de défilement
      u8g.drawBitmapP(128-8, 0, 8/8, 64, bitmap_barre);

      // Emplacement de la barre de défilement
      u8g.drawBox(125, 64/nbr_items * item_actuel, 3, 64/nbr_items);           
    }

    // Ecran amplification
    if (ecran_actuel == 1) {
      // Tour d'item sélectionné
      u8g.drawBitmapP(0, 44, 128/8, 21, bitmap_item_actuel);

      // Police
      u8g.setFont(u8g_font_7x14);

      // Amplification
      u8g.drawStr(25, 15, items_menu[0]); 
      u8g.drawBitmapP(2, 2, 16/8, 16, bitmap_icones[0]);

      // Gain
      u8g.drawStr(4, 37, ("Gain : " + String(gain)).c_str()); 

      // Retour
      u8g.drawStr(25, 59, "Retour");   
      u8g.drawBitmapP(4, 46, 16/8, 16, bitmap_icones[2]);
    }

    // Ecran valeurs
    if (ecran_actuel == 2) {
      int R_flex_int = static_cast<int>((R_flex + 0.5)/1000); // Convertit à l'entier le plus proche
      int R_capt_int = static_cast<int>(R_capt + 0.5); // Convertit à l'entier le plus proche

      // Tour d'item sélectionné
      u8g.drawBitmapP(0, 44, 128/8, 21, bitmap_item_actuel);

      // Police
      u8g.setFont(u8g_font_7x14);

      // Flex
      u8g.drawStr(4, 15, ("Flex : " + String(R_flex_int) + " kOmhs").c_str());

      // Capt
      u8g.drawStr(4, 37, ("Capt : " + String(R_capt_int) + " Omhs").c_str());

      // Retour
      u8g.drawStr(25, 59, "Retour");   
      u8g.drawBitmapP(4, 46, 16/8, 16, bitmap_icones[2]);
    }
  } while (u8g.nextPage()); // Nécessaire
}

// Affiche les annimation
void animation_valide() {
  int nbr_image = 28; // Nombre d'images dans l'annimation
  for (int image = 0; image < nbr_image; ++image) {
    u8g.firstPage(); // Nécessaire
    do {
      u8g.drawBitmapP(40, 8, 6, 48, images_valide[image]); //On affiche les images successivement
    } while (u8g.nextPage()); // Nécessaire
    delay(delai_inter_image); // Pas grave d'avoir un delay ici
  }
}

// Affiche les annimation
void animation_refus() {
  int nbr_image = 28; // Nombre d'images dans l'annimation
  for (int i = 0; i < 2; i++){
    for (int image = 0; image < nbr_image; ++image) {
      u8g.firstPage(); // Nécessaire
      do {
        u8g.drawBitmapP(48, 8, 4, 32, images_refus[image]); //On affiche les images successivement

        u8g.setFont(u8g_font_7x14); // Police

        u8g.drawStr(10, 59, (String(int(gain_min)) + " <= Gain <= " + String(int(gain_max))).c_str()); 

      } while (u8g.nextPage()); // Nécessaire
      delay(delai_inter_image); // Pas grave d'avoir un delay ici
    }
  }
}

// Pour reçevoir le gain s'il a changé
void bluetooth_gain() {
  if (mySerial.available()) { // Si des données sont à recevoir
    String inputString = mySerial.readStringUntil('\n'); // Lit la chaîne jusqu'au retour à la ligne
    int gain_souhaite = inputString.toInt(); // Convertit la chaîne en entier
    if ((gain_souhaite >= gain_min) && (gain_souhaite <= gain_max)) { // Vérifie que le gain demandé est un nombre positif valide
      gain = gain_souhaite; // Mets à jour le gain
      animation_valide(); // Joue l'annimation "validé"
    }
    else animation_refus(); // Joue l'annimation "refus"
  }
}

// Pour envoyer les données en bluetooth
void envoie_bluetooth(float R_capt, float R_flex){
  // Convertit les valeurs entières en chaînes de caractères
  String R_capt_str = String(R_capt);
  String R_flex_str = String(R_flex);

  // Envoie les données au HC-05
  mySerial.println(R_capt_str); // Envoie R_capt suivi d'un retour à la ligne
  mySerial.println(R_capt_str); // Envoie R_capt suivi d'un retour à la ligne
  mySerial.println(R_flex_str); // Envoie R_flex suivi d'un retour à la ligne
}

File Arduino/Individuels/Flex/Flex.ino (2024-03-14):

const int Flex = A1;      // Pin connected to voltage divider output

// Change these constants according to your project's design
const float VCC = 5;      // voltage at Ardunio 5V line
const float R_DIV = 47000.0;  // resistor used to create a voltage divider
const float R_plat = 25000.0; // resistance when flat
const float R_pli = 100000.0;  // resistance at 90 deg

void setup() {
  Serial.begin(9600);
  pinMode(Flex, INPUT);
}

void loop() {
  float flex_angle = Flex_read();
  Serial.println(flex_angle);
}

float Flex_read() {
  float Vflex = analogRead(Flex) * VCC / 1023.0; // Lecture de la tension aux bornes du FLEX
  float Rflex = R_DIV * (VCC / Vflex - 1.0); // Calcul de la résistance du FLEX
  return (Rflex - R_plat) * (90.0 - 0) / (R_pli - R_plat) + 0; // Estimation de l'angle du FLEX
}

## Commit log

2024-03-08 Bon format de readme
2024-03-08 Nouveau README.md
    Ajout d'émojis pour rendre le readme plus vivant.
    Changement du titre, des auteurs et du contexte
    Ajout du centrage des textes
2024-03-08 GIF de présentation du PCB
2024-03-08 Nouveau README.md
    GIF de présentation
2024-03-08 Ajout des fichiers KiCad
    [Flex.stp, KY-040.step, Kicad Projet Capteur.kicad_pcb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]
2024-03-08 Nouveau README.md
    Ajout des liens
    Quelques changements de texte
2024-03-08 Gif pour la présentation du PCB
    Boucle parfaite
2024-03-08 Ajout des fichiers Arduino
    1ère version avec juste les initialisations
2024-03-11 Amélioration layout KiCad
    OLED +
    [Kicad Projet Capteur.kicad_pcb, Kicad Projet Capteur.kicad_sch, Kicad Projet Capteur_copie.kicad_pcb]
2024-03-11 Nouveau PCB + Nouveau GIF
    Plan de masse un peu plus propre et mise à jour du GIF
    [Kicad Projet Capteur.kicad_pcb, Kicad Projet Capteur_copie.kicad_pcb]
2024-03-13 Update Capteur.aia
    Changement nom de variables
2024-03-14 fonctions bluetooth arduino + appli
    Création fonctions bluetooth arduino + ajout graphe flex sensor pour l'appplication
    [Arduino.ino]
2024-03-14 Ajout du flex et de l'encodeur + bluetooth corrigé
    [Arduino.ino, Encodeur.ino, Flex.ino]
2024-03-14 Ajout capteur + OLED avec menus + switch
2024-03-14 Nouveau README.md
    Correction des librairies utilisées
2024-03-16 Fix bluetooth + animations
    [Arduino.ino]
2024-03-18 Fix du MCP41050
    - Mappage corrigé
    - Passage en double
    - Gestion plus simple du SPI
    [Arduino.ino, MCP41050.ino]
2024-05-12 Added datasheet, fixed ground plane
    [Kicad Projet Capteur.kicad_pcb]

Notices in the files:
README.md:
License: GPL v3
